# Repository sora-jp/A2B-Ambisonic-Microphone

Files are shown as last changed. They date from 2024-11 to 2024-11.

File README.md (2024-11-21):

# Passive Sonar / Ambisonic Microphone
This repo contains a design for a working ambisonic microphone, based on AD2427W A2B transcievers, along with Infineon IM73D122V01XTMA1 MEMS microphones.

## Structure
- kicad_micboard/ : Design files for the microphone board (firmware supports up to 16 of these)
- kicad_iface/ : Design files for the MCHStreamer interface board (only one of these needed)
- firmware_iface/ : Firmware for the MCHStreamer interface board

These folders each contain a README.md, describing their contents in more detail, along with an ORDERING.md giving details on how to order each board.

## Cabling
The cables between nodes are **straight-through twisted pair 2-pin JST-PH** cables. I crimped these cables myself, but you could easily order single-ended pre-crimped cables and then twist and solder them manually

## Known issues
- The voltage given to the interface board dictates how many nodes you can connect in series. For 5 volts, it can only support 6 nodes. For 15 nodes, you need to power the interface board with between 8V and 9V. It will *probably* work on 10V, but won't work on 12V. Some cheap 9V power supplies output *way* more than 9V when unloaded, so be careful with what power supply you choose.
- The A2B transciever on the interface board is missing connections for the I2C address lines. In theory, the actual I2C address of the transciever is undefined, in practice it works. If it doesn't, change the I2C address in the firmware.

## Future work
- The microphone boards have an expansion port, allowing the system to support up to 32 microphones (in theory, this hasn't been tested). The daughter-board to connect to said port hasn't been designed yet.
- The firmware is still very early, and doesn't correctly handle every edgecase. Ideally it should do line-fault diagnostics, but this is currently not implemented.

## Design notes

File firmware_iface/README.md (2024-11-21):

# Interface firmware
The following is a step-by-step guide on how to install and use the firmware.

## Building
To build the firmware from souce, first install `avr-gcc`, `avrdude`, `cmake`, and `make`
Then, run the following commands in this folder:
```sh
mkdir -p build
cd build
cmake ..
make
```

## Setting the fuses
The AVR microcontroller on the interface board needs the correct fuses programmed to work. This is handled automatically when flashing the board using `make flash`

## Flashing
To flash the firmware, first connect your AVRISP-MKII to the interface board. Make sure you are supplying 9V power to the interface board. Then, run `make flash` inside the build directory

## NixOS
If you are using Nix / running NixOS, you can use the included flake to install all necessary dependencies. Simply run `nix develop .#` in this directory, and all necessary tools will be installed and made available in your current shell.

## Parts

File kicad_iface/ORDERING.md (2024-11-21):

# Interface board ordering notes

I ordered this from JLCPCB with great success, and with the following non-default parameters:

- Impedance controlled: Yes
- Stackup: JLC7628
- Assembly: Yes
- Economic assembly (standard works but is more costly)

You might need standard assembly if you want JLC to solder the headers for you. Important to note that the headers (only the 2mm pitch ones, not the terminal block) are placed on the back side of the PCB.

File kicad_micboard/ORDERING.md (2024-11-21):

# Microphone board ordering notes

I ordered this from JLCPCB with the following non-standard parameters:

- Impedance controlled: Yes
- Stackup: JLC7628
- Assembly: Yes
- Economic assembly (standard works but is more costly)

All components can be placed with economic assembly

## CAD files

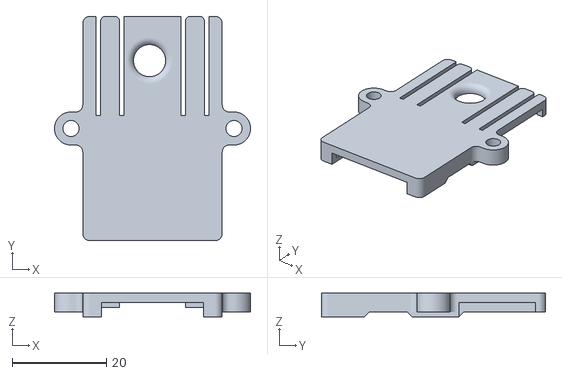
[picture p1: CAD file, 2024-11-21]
holder_cad/Backplane.obj
41.6 x 47.6 x 5.00

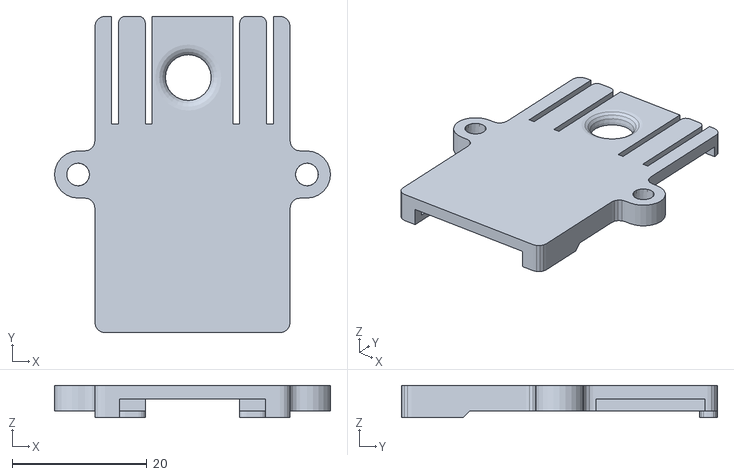
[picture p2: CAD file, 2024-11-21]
holder_cad/PassiveSonar/Backplane.obj
41.0 x 47.0 x 4.80

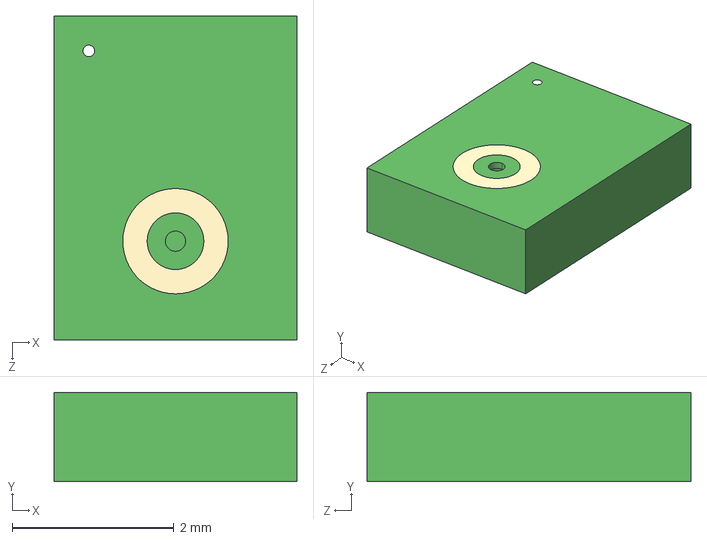
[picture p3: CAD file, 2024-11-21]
kicad_micboard/MP34DT06J.STEP
3.00 x 1.10 x 4.00 mm

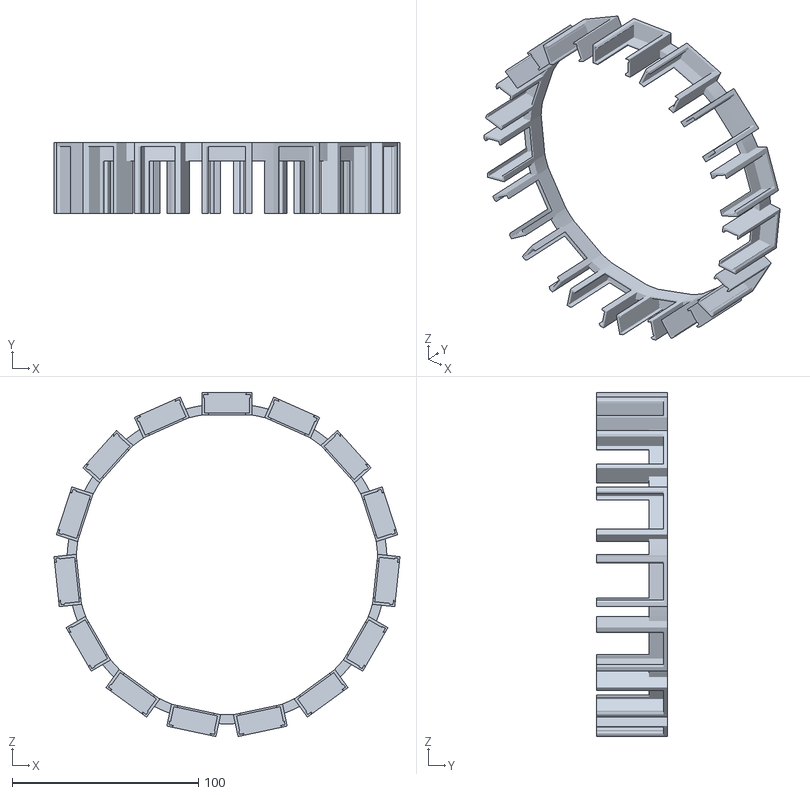
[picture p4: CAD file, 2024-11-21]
holder_cad/Sphere_V2.obj
185.8 x 38.0 x 184.8

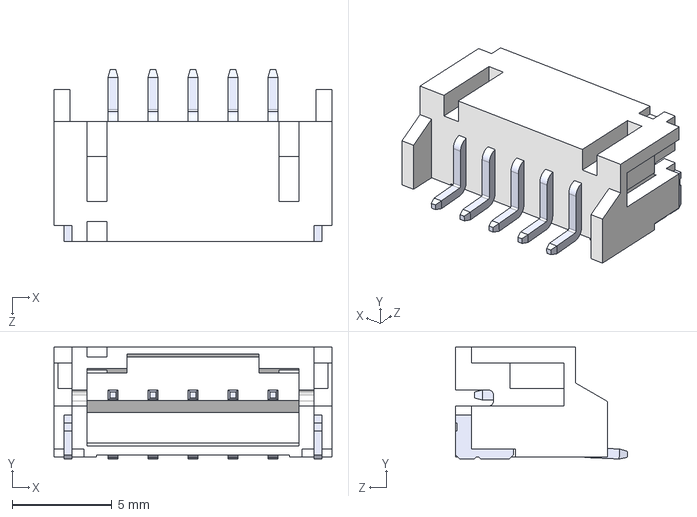
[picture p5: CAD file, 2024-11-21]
kicad_micboard/S5B-PH-SM4-TB--3DModel-STEP-56544.STEP
13.9 x 5.60 x 8.60 mm

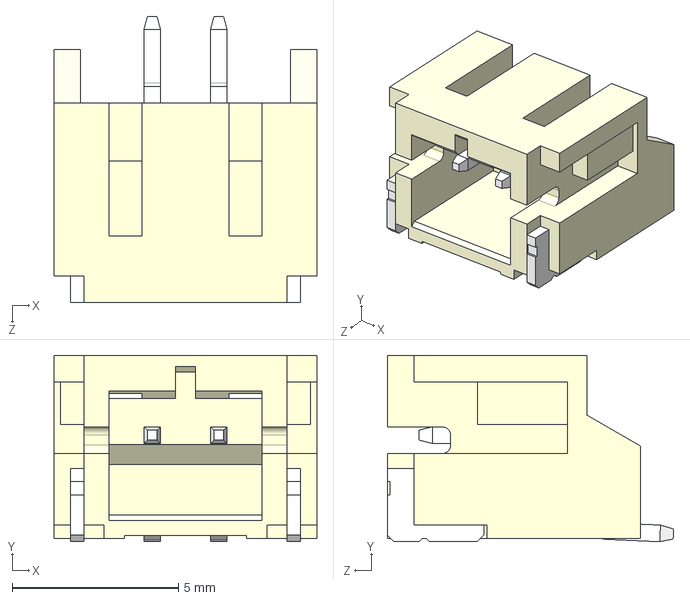
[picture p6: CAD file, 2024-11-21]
kicad_micboard/S2B-PH-SM4-TB--3DModel-STEP-269445.STEP
7.90 x 5.60 x 8.60 mm

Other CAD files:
holder_cad/Backplane.ipt
holder_cad/Backplate.ipt
holder_cad/PassiveSonar/PassiveSonar/ACT1210L-201-2P-TL00--3DModel-STEP-269445.iam
holder_cad/PassiveSonar/PassiveSonar/C_0402_1005Metric.iam
holder_cad/PassiveSonar/PassiveSonar/C_0402_1005Metric.ipt
holder_cad/PassiveSonar/PassiveSonar/C_0603_1608Metric.iam
holder_cad/PassiveSonar/PassiveSonar/C_0603_1608Metric.ipt
holder_cad/PassiveSonar/PassiveSonar/C_0805_2012Metric.iam
holder_cad/PassiveSonar/PassiveSonar/C_0805_2012Metric.ipt
holder_cad/PassiveSonar/PassiveSonar/D_SMA.iam
holder_cad/PassiveSonar/PassiveSonar/D_SMA.ipt
holder_cad/PassiveSonar/PassiveSonar/LED_0603_1608Metric.iam
holder_cad/PassiveSonar/PassiveSonar/LED_0603_1608Metric.ipt
holder_cad/PassiveSonar/PassiveSonar/L_0805_2012Metric.iam
holder_cad/PassiveSonar/PassiveSonar/L_0805_2012Metric.ipt
holder_cad/PassiveSonar/PassiveSonar/PassiveSonar_PCB.ipt
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

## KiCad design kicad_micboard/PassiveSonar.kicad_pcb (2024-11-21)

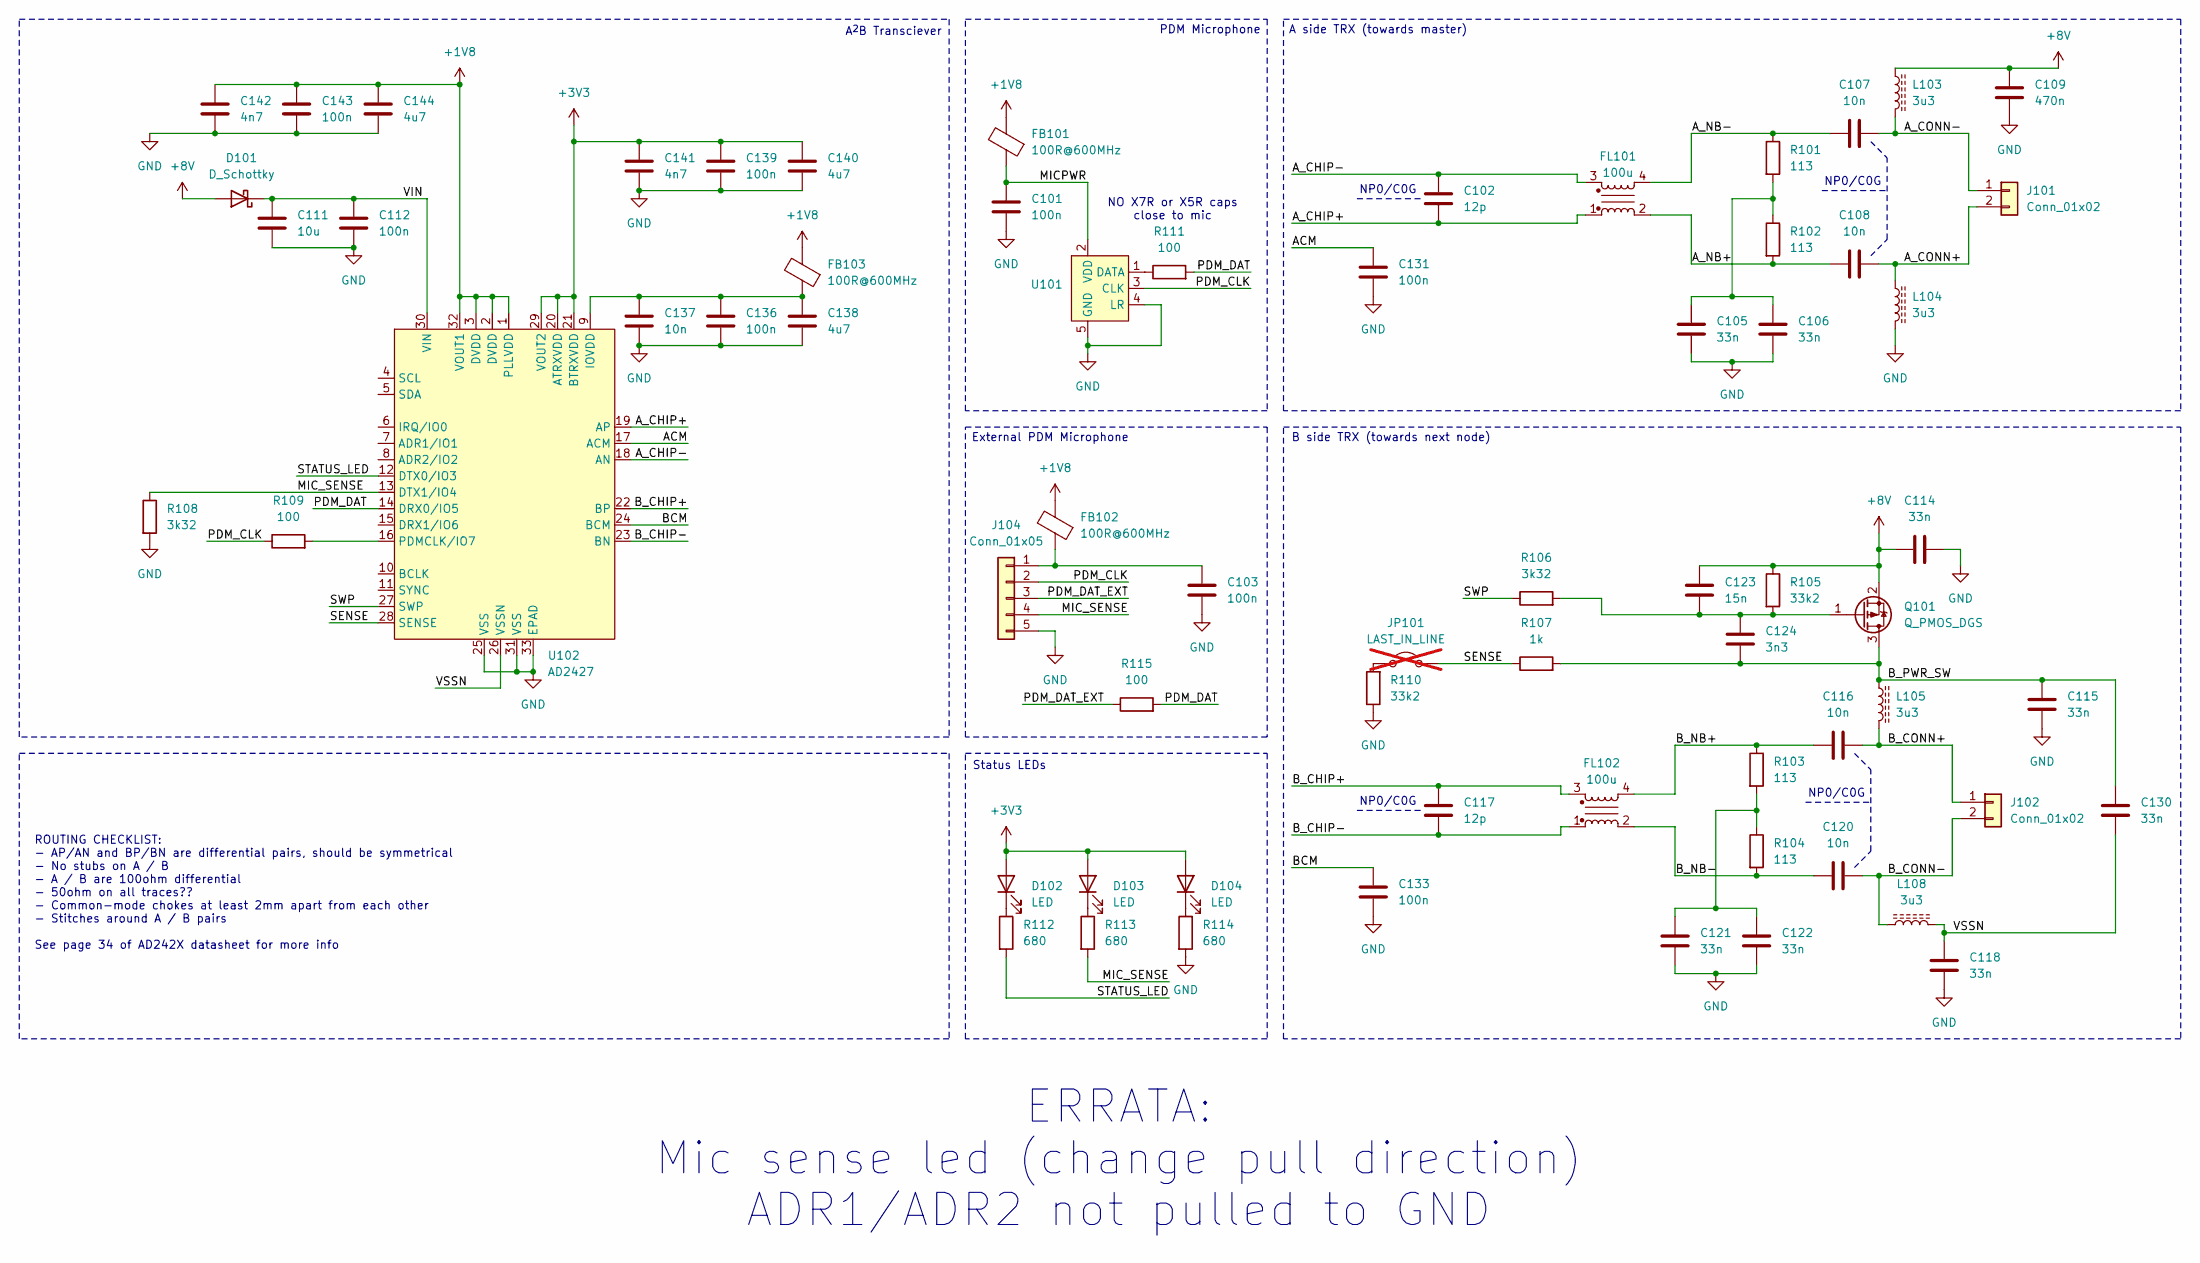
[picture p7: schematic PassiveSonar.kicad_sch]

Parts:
C101, C103, C112, C131, C133, C136, C139, C143: 100n; C_0402_1005Metric; JLC 0402
C102, C117: 12p; C_0402_1005Metric; JLC 0402
C105, C106, C114, C115, C118, C121, C122, C130: 33n; C_0603_1608Metric; JLC 0603
C107, C108, C116, C120, C137: 10n; C_0402_1005Metric; JLC 0402
C109: 470n; C_0805_2012Metric; JLC 0805
C111: 10u; C_0805_2012Metric; JLC 0805
C123: 15n; C_0603_1608Metric; JLC 0603
C124: 3n3; C_0402_1005Metric; JLC 0402
C138, C140, C144: 4u7; C_0603_1608Metric; JLC 0603
C141, C142: 4n7; C_0402_1005Metric; JLC 0402
D101: D_Schottky; D_SMA; JLC SMA(DO-214AC)
D102, D103, D104: LED; LED_0603_1608Metric; JLC 0603
FB101, FB102, FB103: 100R@600MHz; R_0603_1608Metric; JLC 0603
FL101, FL102: 100u; TDK-ACT1210L-101-2P-TL00; JLC SMD,3.9x2.5x2.5mm
J101, J102: Conn_01x02; JST_PH_S2B-PH-SM4-TB_1x02-1MP_P2.00mm_Horizontal; JLC SMD,P=2mm
J104: Conn_01x05; JST_PH_S5B-PH-SM4-TB_1x05-1MP_P2.00mm_Horizontal; JLC SMD
JP101: LAST_IN_LINE; PinHeader_1x02_P1.27mm_Vertical; not fitted
L103, L104, L105, L108: 3u3; L_0805_2012Metric; JLC 0805
Q101: Q_PMOS_DGS; SOT-23; JLC SOT-23
R101, R102, R103, R104: 113; R_0603_1608Metric; JLC 0603
R105, R110: 33k2; R_0402_1005Metric; JLC 0402
R106, R108: 3k32; R_0402_1005Metric; JLC 0402
R107: 1k; R_0402_1005Metric; JLC 0402
R109, R111, R115: 100; R_0402_1005Metric; JLC 0402
R112, R113, R114: 680; R_0402_1005Metric; JLC 0402
U101: Infineon_PG-LLGA-5-1; JLC SMD
U102: AD2427; LFCSP-32-1EP_5x5mm_P0.5mm_EP3.5x3.5mm; JLC LFCSP-32-SS(5x5)

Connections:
+1V8: C142.1, C143.1, C144.1, FB101.2, FB102.2, FB103.2, U102.1 (PLLVDD), U102.2 (DVDD), U102.3 (DVDD), U102.32 (VOUT1)
+3V3: C139.1, C140.1, C141.1, D102.2 (A), D103.2 (A), D104.2 (A), U102.20 (ATRXVDD), U102.21 (BTRXVDD), U102.29 (VOUT2)
+8V: C109.1, C114.1, C123.1, D101.2 (A), L103.1, Q101.2 (S), R105.1
/ACM: C131.1, U102.17 (ACM)
/A_CHIP+: C102.1, FL101.1, U102.19 (AP)
/A_CHIP-: C102.2, FL101.3, U102.18 (AN)
/A_CONN+: C108.1, J101.2, L104.1
/A_CONN-: C107.1, J101.1, L103.2
/A_NB+: C108.2, FL101.2, R102.2
/A_NB-: C107.2, FL101.4, R101.1
/BCM: C133.1, U102.24 (BCM)
/B_CHIP+: C117.2, FL102.3, U102.22 (BP)
/B_CHIP-: C117.1, FL102.1, U102.23 (BN)
/B_CONN+: C116.1, J102.1, L105.2
/B_CONN-: C120.1, J102.2, L108.1
/B_NB+: C116.2, FL102.4, R103.1
/B_NB-: C120.2, FL102.2, R104.2
/B_PWR_SW: C115.1, C124.2, C130.1, L105.1, Q101.3 (D), R107.2
/MICPWR: C101.2, FB101.1, U101.2 (VDD)
/MIC_SENSE: J104.4, R108.1, R113.2, U102.13 (DTX1/IO4)
/PDM_CLK: J104.2, R109.1, U101.3 (CLK)
/PDM_DAT: R111.2, R115.2, U102.14 (DRX0/IO5)
/PDM_DAT_EXT: J104.3, R115.1
/SENSE: JP101.2 (B), R107.1, U102.28 (SENSE)
/STATUS_LED: R112.2, U102.12 (DTX0/IO3)
/SWP: R106.1, U102.27 (SWP)
/VIN: C111.1, C112.1, D101.1 (K), U102.30 (VIN)
/VSSN: C118.1, C130.2, L108.2, U102.26 (VSSN)
GND: C101.1, C103.1, C105.1, C106.1, C109.2, C111.2, C112.2, C114.2, C115.2, C118.2, C121.1, C122.1, C131.2, C133.2, C136.2, C137.2, C138.2, C139.2, C140.2, C141.2, C142.2, C143.2, C144.2, J104.5, L104.2, R108.2, R110.1, R114.2, U101.4 (LR), U101.5 (GND), U102.25 (VSS), U102.31 (VSS), U102.33 (EPAD)
unnamed: C105.2, C106.2, R101.2, R102.1
unnamed: C121.2, C122.2, R103.2, R104.1
unnamed: D102.1 (K), R112.1
unnamed: D103.1 (K), R113.1
unnamed: D104.1 (K), R114.1
unnamed: C103.2, FB102.1, J104.1
unnamed: JP101.1 (A), R110.2
unnamed: C123.2, C124.1, Q101.1 (G), R105.2, R106.2
unnamed: R111.1, U101.1 (DATA)
unnamed: C136.1, C137.1, C138.1, FB103.1, U102.9 (IOVDD)
unnamed: R109.2, U102.16 (PDMCLK/IO7)

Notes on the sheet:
B side TRX (towards next node)
Status LEDs
ROUTING CHECKLIST: - AP/AN and BP/BN are differential pairs, should be symmetrical - No stubs on A / B - A / B are 100ohm differential - 50ohm on all traces?? - Common-mode chokes at least 2mm apart from each other - Stitches around A / B pairs See page 34 of AD242X datasheet for more info
NP0/C0G
A^{2}B Transciever
A side TRX (towards master)
PDM Microphone
NO X7R or X5R caps close to mic
External PDM Microphone
ERRATA: Mic sense led (change pull direction) ADR1/ADR2 not pulled to GND

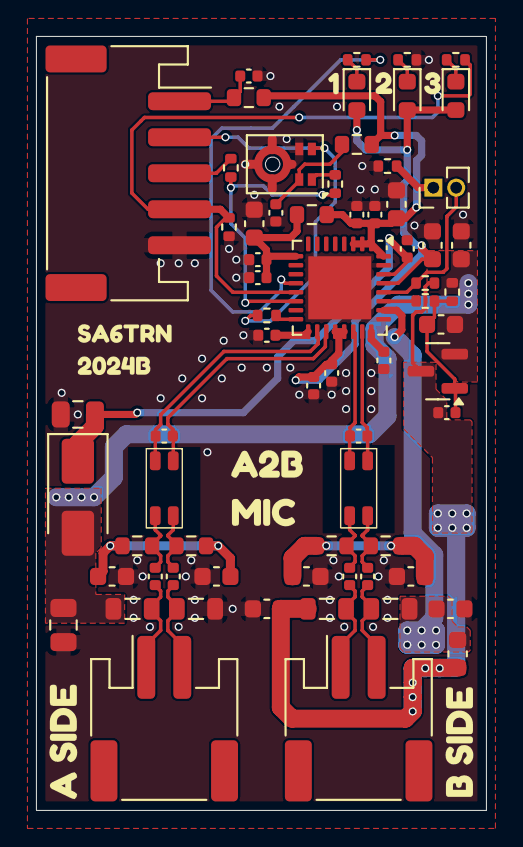
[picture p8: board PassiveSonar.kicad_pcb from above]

Board: 4 copper layers, 25.0 x 43.0 mm, 74 parts (0 on the bottom side), 40 nets.

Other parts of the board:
kibuzzard-66BA53B9: G***; kibuzzard-66BA53B9
kibuzzard-66BA534A: G***; kibuzzard-66BA534A
kibuzzard-66BA542A: G***; kibuzzard-66BA542A
kibuzzard-66BA5330: G***; kibuzzard-66BA5330
kibuzzard-66BA5382: G***; kibuzzard-66BA5382
kibuzzard-66BA5389: G***; kibuzzard-66BA5389
kibuzzard-66BA5390: G***; kibuzzard-66BA5390

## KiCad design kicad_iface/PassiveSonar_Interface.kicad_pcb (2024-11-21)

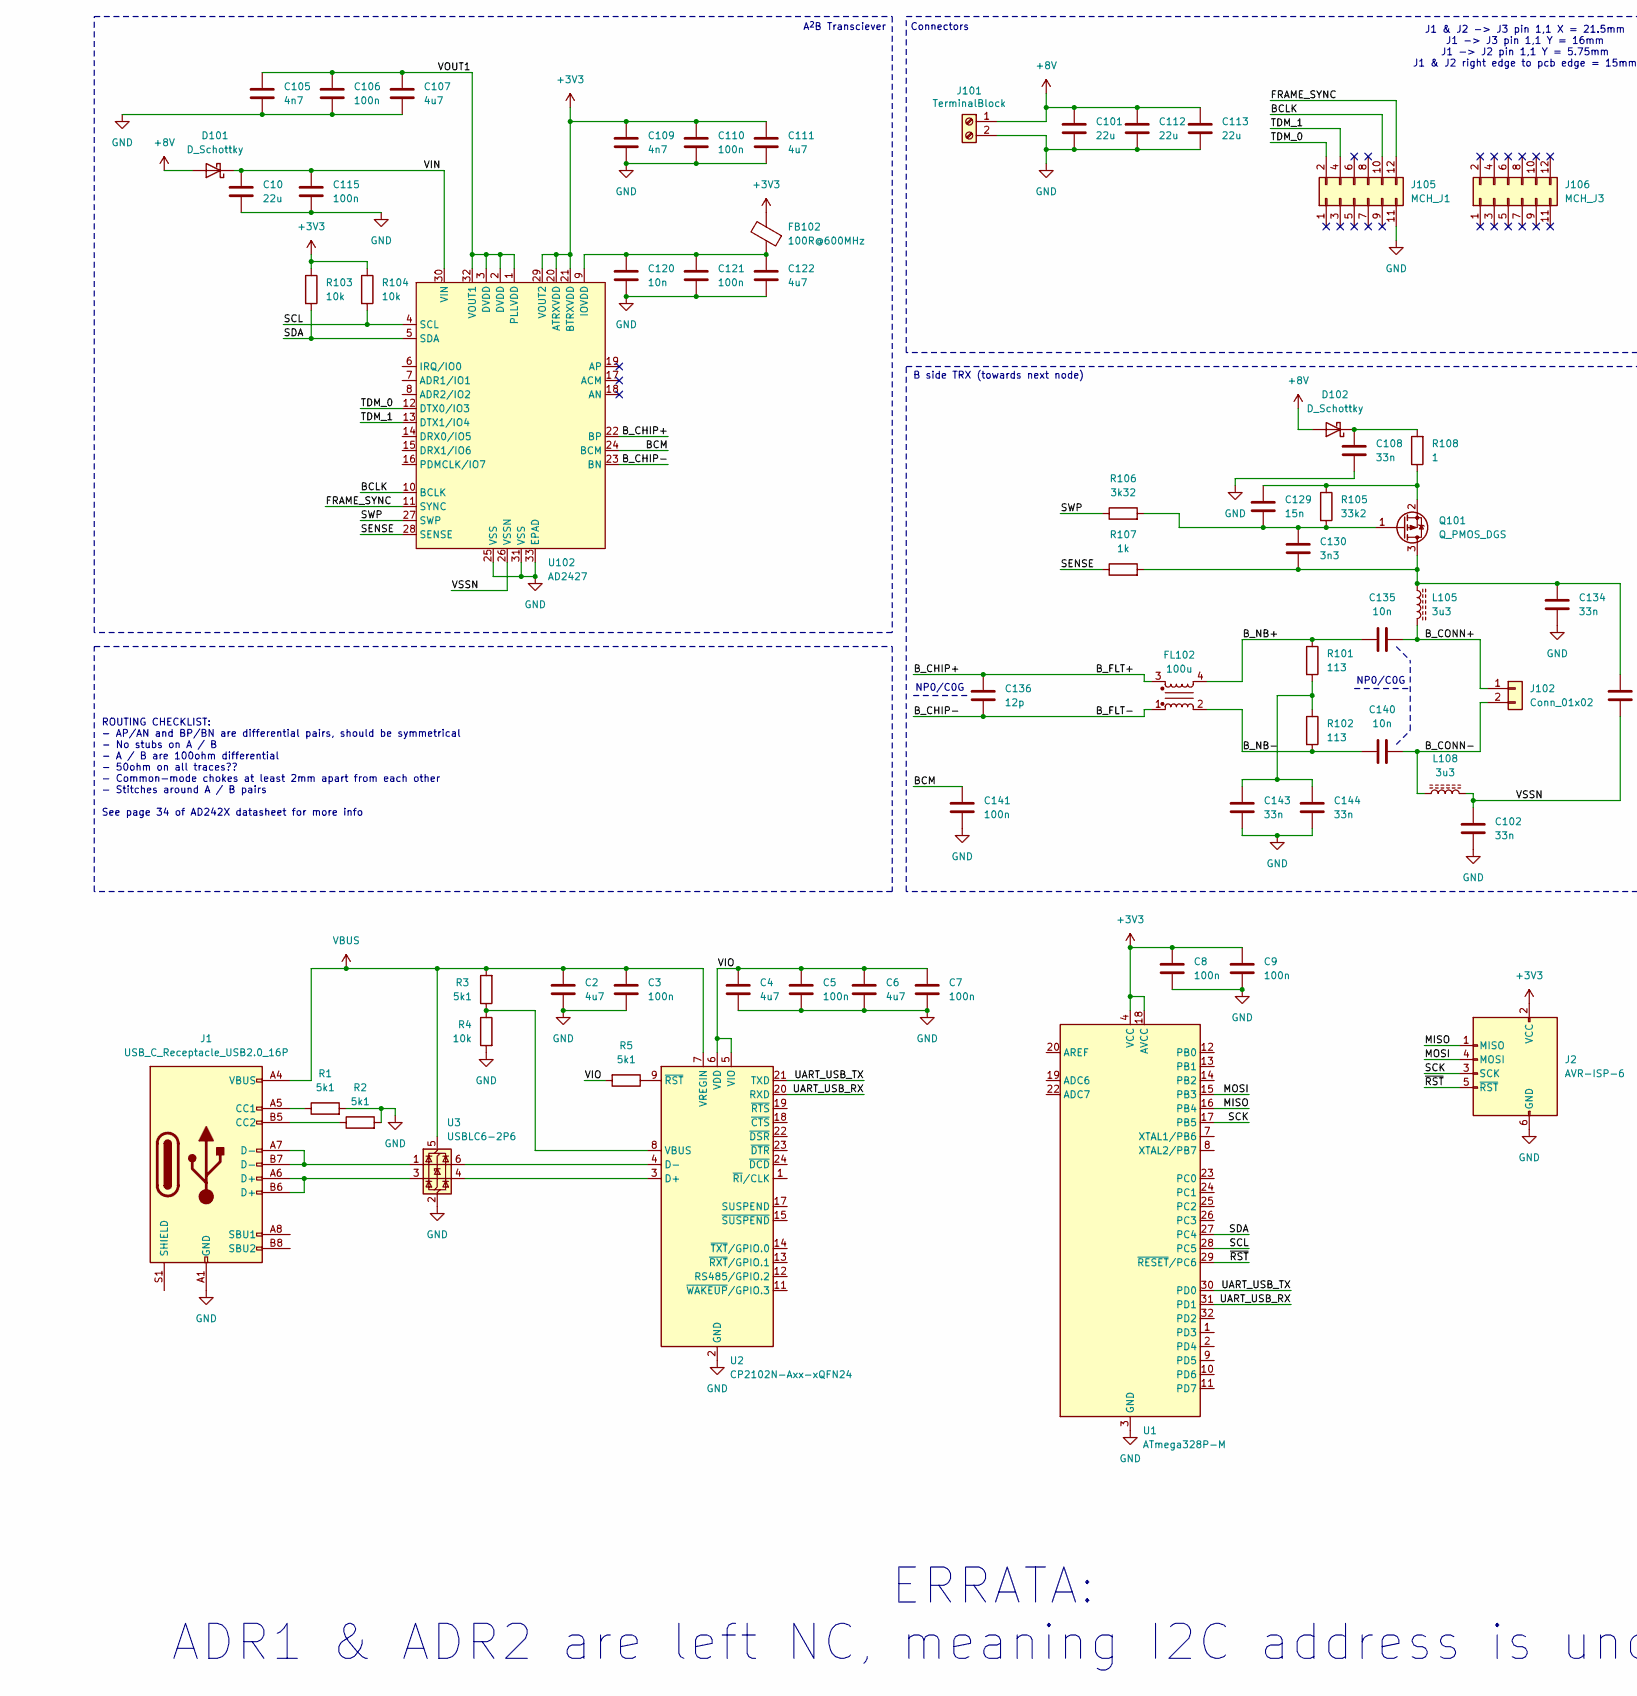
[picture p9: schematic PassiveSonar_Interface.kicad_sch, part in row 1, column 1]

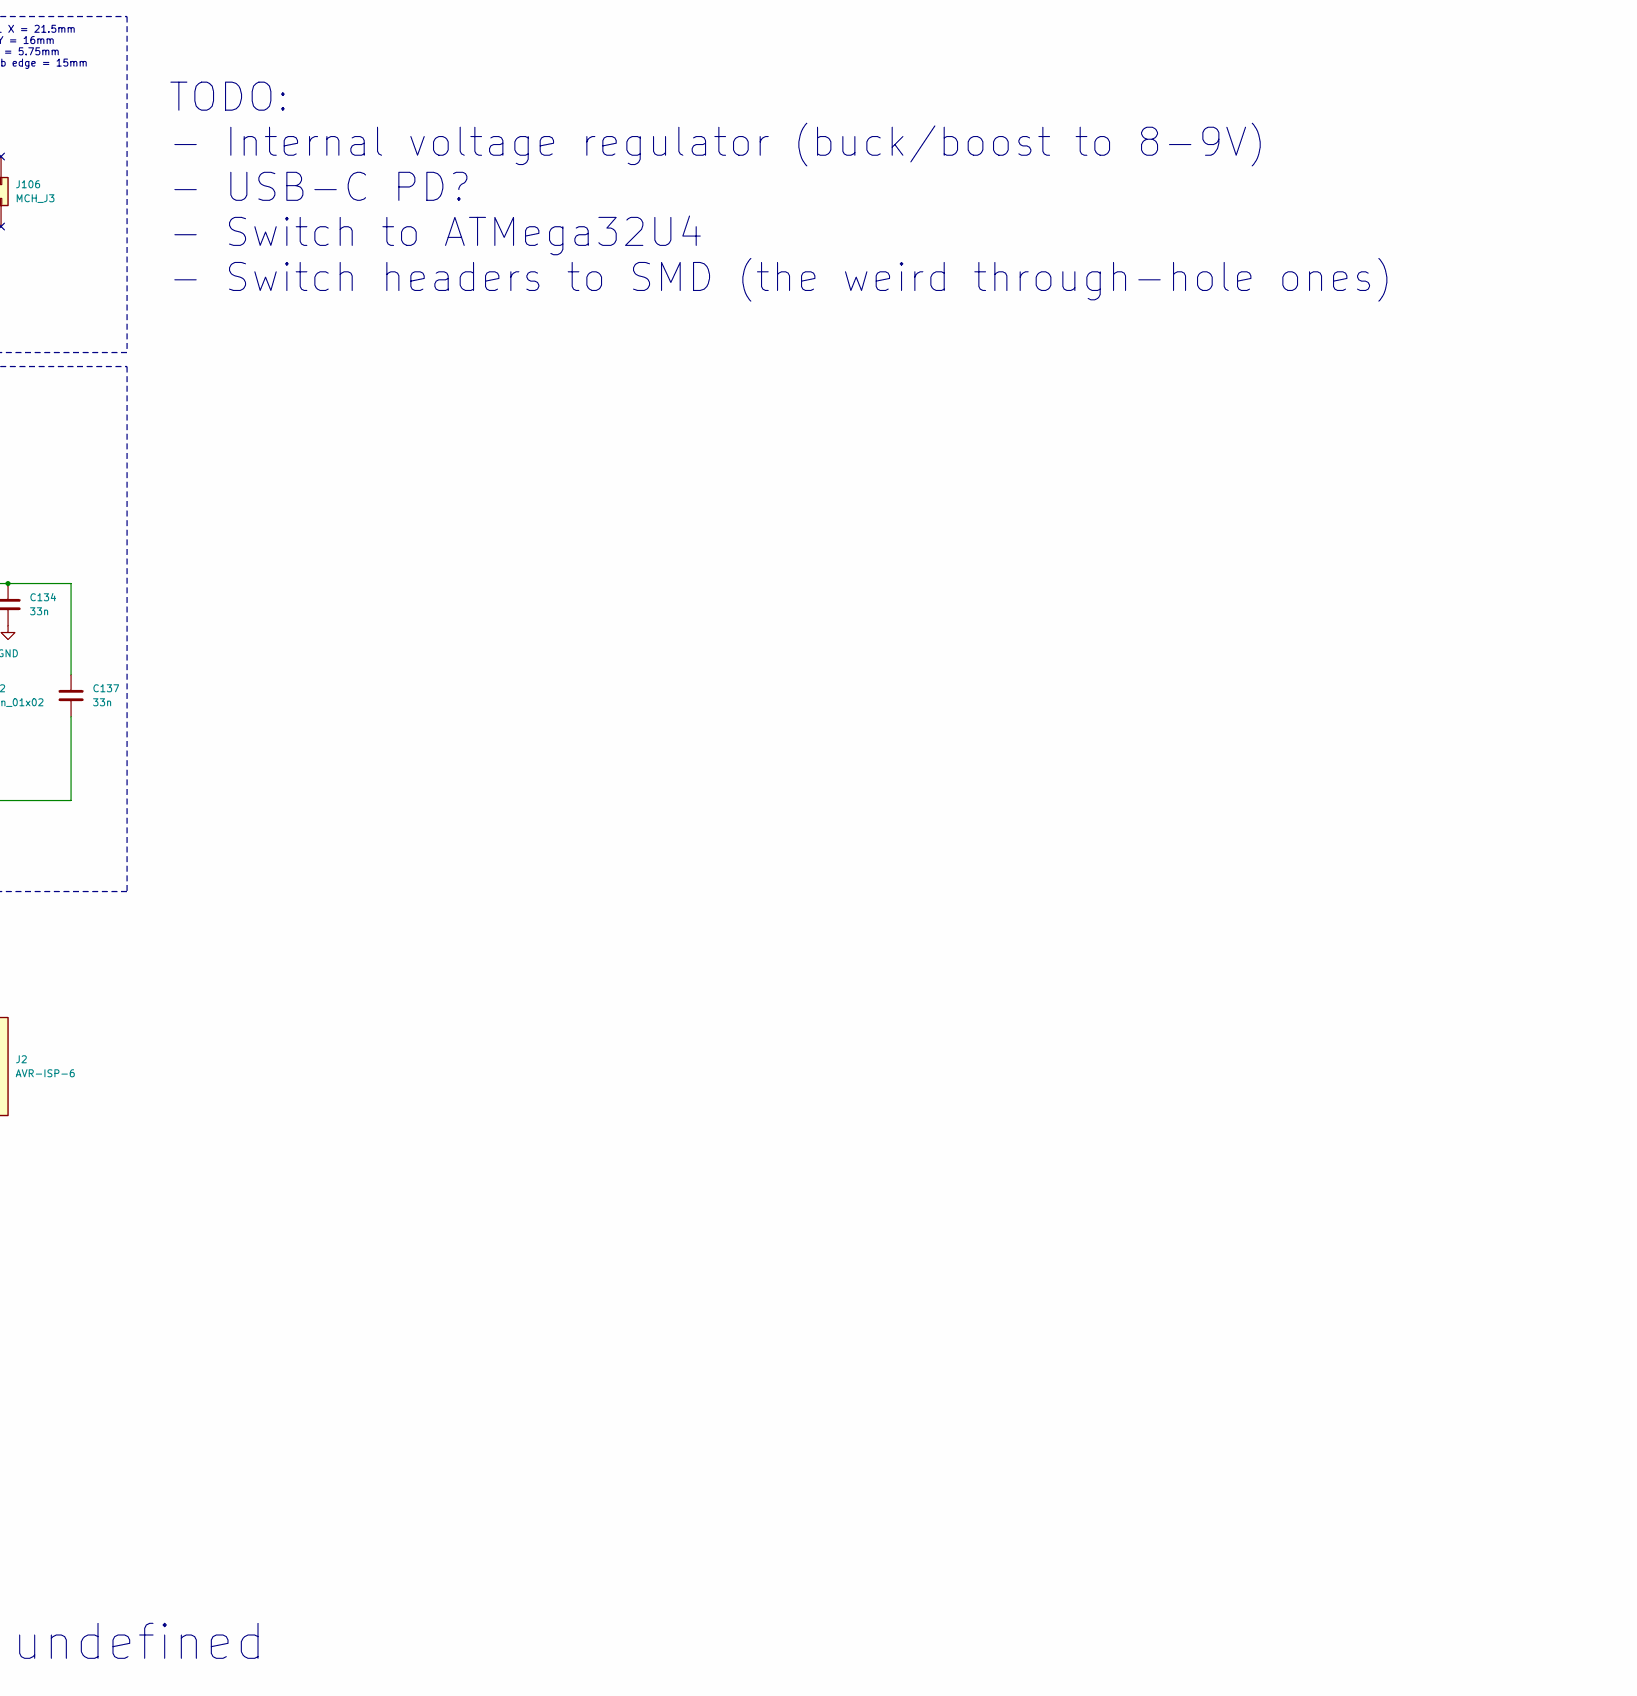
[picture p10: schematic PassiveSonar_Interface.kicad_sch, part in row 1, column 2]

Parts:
C2, C4, C6, C107, C111, C122: 4u7; C_0603_1608Metric; JLC 0603
C3, C5, C7, C8, C9, C106, C110, C115, C121, C141: 100n; C_0402_1005Metric; JLC 0402
C10, C101, C112, C113: 22u; C_0805_2012Metric; JLC 0805
C102, C108, C134, C137, C143, C144: 33n; C_0603_1608Metric; JLC 0603
C105, C109: 4n7; C_0402_1005Metric; JLC 0402
C120, C135, C140: 10n; C_0402_1005Metric; JLC 0402
C129: 15n; C_0603_1608Metric; JLC 0603
C130: 3n3; C_0402_1005Metric; JLC 0402
C136: 12p; C_0402_1005Metric; JLC 0402
D101, D102: D_Schottky; D_SMA; JLC SMA(DO-214AC)
FB102: 100R@600MHz; R_0603_1608Metric; JLC 0603
FL102: 100u; TDK-ACT1210L-101-2P-TL00; JLC SMD,3.9x2.5x2.5mm
J1: USB_C_Receptacle_USB2.0_16P; USB_C_Receptacle_HRO_TYPE-C-31-M-12; JLC SMD
J2: AVR-ISP-6; PinHeader_2x03_P2.54mm_Vertical_SMD; LCSC C124390
J101: TerminalBlock; TerminalBlock_Phoenix_MKDS-1,5-2_1x02_P5.00mm_Horizontal
J102: Conn_01x02; JST_PH_S2B-PH-SM4-TB_1x02-1MP_P2.00mm_Horizontal; JLC SMD,P=2mm
J105: MCH_J1; PinSocket_2x06_P2.00mm_Vertical; Mouser 872631223
J106: MCH_J3; PinSocket_2x06_P2.00mm_Vertical; Mouser 872631223
L105, L108: 3u3; L_0805_2012Metric; JLC 0805
Q101: Q_PMOS_DGS; SOT-23; JLC SOT-23
R1, R2, R3, R5: 5k1; R_0402_1005Metric; JLC 0402
R4, R103, R104: 10k; R_0402_1005Metric; JLC 0402
R101, R102: 113; R_0603_1608Metric; JLC 0603
R105: 33k2; R_0402_1005Metric; JLC 0402
R106: 3k32; R_0402_1005Metric; JLC 0402
R107: 1k; R_0402_1005Metric; JLC 0402
R108: 1; R_1206_3216Metric; JLC 1206
U1: ATmega328P-M; QFN-32-1EP_5x5mm_P0.5mm_EP3.1x3.1mm; JLC VQFN-32(5x5)
U2: CP2102N-Axx-xQFN24; QFN-24-1EP_4x4mm_P0.5mm_EP2.6x2.6mm; JLC QFN-24-EP(4x4)
U3: USBLC6-2P6; SOT-666; JLC SOT-666-6
U102: AD2427; LFCSP-32-1EP_5x5mm_P0.5mm_EP3.5x3.5mm; JLC LFCSP-32-SS(5x5)

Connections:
+3V3: C8.1, C9.1, C109.1, C110.1, C111.1, FB102.2, J2.2 (VCC), R103.1, R104.1, U1.4 (VCC), U1.6 (VCC), U1.18 (AVCC), U102.20 (ATRXVDD), U102.21 (BTRXVDD), U102.29 (VOUT2)
+8V: C101.1, C112.1, C113.1, D101.2 (A), D102.2 (A), J101.1
/BCLK: J105.10, U102.10 (BCLK)
/BCM: C141.1, U102.24 (BCM)
/B_CHIP+: C136.2, FL102.3, U102.22 (BP)
/B_CHIP-: C136.1, FL102.1, U102.23 (BN)
/B_CONN+: C135.1, J102.1, L105.2
/B_CONN-: C140.1, J102.2, L108.1
/B_NB+: C135.2, FL102.4, R101.1
/B_NB-: C140.2, FL102.2, R102.2
/FRAME_SYNC: J105.12, U102.11 (SYNC)
/MISO: J2.1 (MISO), U1.16 (PB4)
/MOSI: J2.4 (MOSI), U1.15 (PB3)
/SCK: J2.3 (SCK), U1.17 (PB5)
/SCL: R104.2, U1.28 (PC5), U102.4 (SCL)
/SDA: R103.2, U1.27 (PC4), U102.5 (SDA)
/SENSE: R107.1, U102.28 (SENSE)
/SWP: R106.1, U102.27 (SWP)
/TDM_0: J105.2, U102.12 (DTX0/IO3)
/TDM_1: J105.4, U102.13 (DTX1/IO4)
/UART_USB_RX: U1.31 (PD1), U2.20 (RXD)
/UART_USB_TX: U1.30 (PD0), U2.21 (TXD)
/VIN: C10.1, C115.1, D101.1 (K), U102.30 (VIN)
/VIO: C4.1, C5.1, C6.1, C7.1, R5.2, U2.5 (VIO), U2.6 (VDD)
/VOUT1: C105.1, C106.1, C107.1, U102.1 (PLLVDD), U102.2 (DVDD), U102.3 (DVDD), U102.32 (VOUT1)
/VSSN: C102.1, C137.2, L108.2, U102.26 (VSSN)
/~RST: J2.5 (~RST), U1.29 (~RESET/PC6)
GND: C2.2, C3.2, C4.2, C5.2, C6.2, C7.2, C8.2, C9.2, C10.2, C101.2, C102.2, C105.2, C106.2, C107.2, C108.1, C109.2, C110.2, C111.2, C112.2, C113.2, C115.2, C120.2, C121.2, C122.2, C134.2, C141.2, C143.1, C144.1, J1.A1 (GND), J1.A12 (GND), J1.B1 (GND), J1.B12 (GND), J2.6 (GND), J101.2, J105.11, R1.2, R2.2, R4.2, U1.3 (GND), U1.5 (GND), U1.21 (GND), U1.33 (GND), U2.2 (GND), U2.25 (GND), U3.2 (GND), U102.25 (VSS), U102.31 (VSS), U102.33 (EPAD)
unnamed: C143.2, C144.2, R101.2, R102.1
unnamed: C108.2, D102.1 (K), R108.2
unnamed: J1.A5 (CC1), R1.1
unnamed: J1.B5 (CC2), R2.1
unnamed: J1.A6 (D+), J1.B6 (D+), U3.3 (I/O2)
unnamed: J1.A7 (D-), J1.B7 (D-), U3.1 (I/O1)
unnamed: C130.2, C134.1, C137.1, L105.1, Q101.3 (D), R107.2
unnamed: C129.2, C130.1, Q101.1 (G), R105.2, R106.2
unnamed: C129.1, Q101.2 (S), R105.1, R108.1
unnamed: U2.3 (D+), U3.4 (I/O2)
unnamed: U2.4 (D-), U3.6 (I/O1)
unnamed: R3.1, R4.1, U2.8 (VBUS)
unnamed: R5.1, U2.9 (~RST)
unnamed: C120.1, C121.1, C122.1, FB102.1, U102.9 (IOVDD)
VBUS: C2.1, C3.1, J1.A4 (VBUS), J1.A9 (VBUS), J1.B4 (VBUS), J1.B9 (VBUS), R3.2, U2.7 (VREGIN), U3.5 (VBUS)

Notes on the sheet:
Connectors
ROUTING CHECKLIST: - AP/AN and BP/BN are differential pairs, should be symmetrical - No stubs on A / B - A / B are 100ohm differential - 50ohm on all traces?? - Common-mode chokes at least 2mm apart from each other - Stitches around A / B pairs See page 34 of AD242X datasheet for more info
B side TRX (towards next node)
TODO: - Internal voltage regulator (buck/boost to 8-9V) - USB-C PD? - Switch to ATMega32U4 - Switch headers to SMD (the weird through-hole ones)
A^{2}B Transciever
NP0/C0G
ERRATA: ADR1 & ADR2 are left NC, meaning I2C address is undefined
J1 & J2 -> J3 pin 1,1 X = 21.5mm J1 -> J3 pin 1,1 Y = 16mm J1 -> J2 pin 1,1 Y = 5.75mm J1 & J2 right edge to pcb edge = 15mm

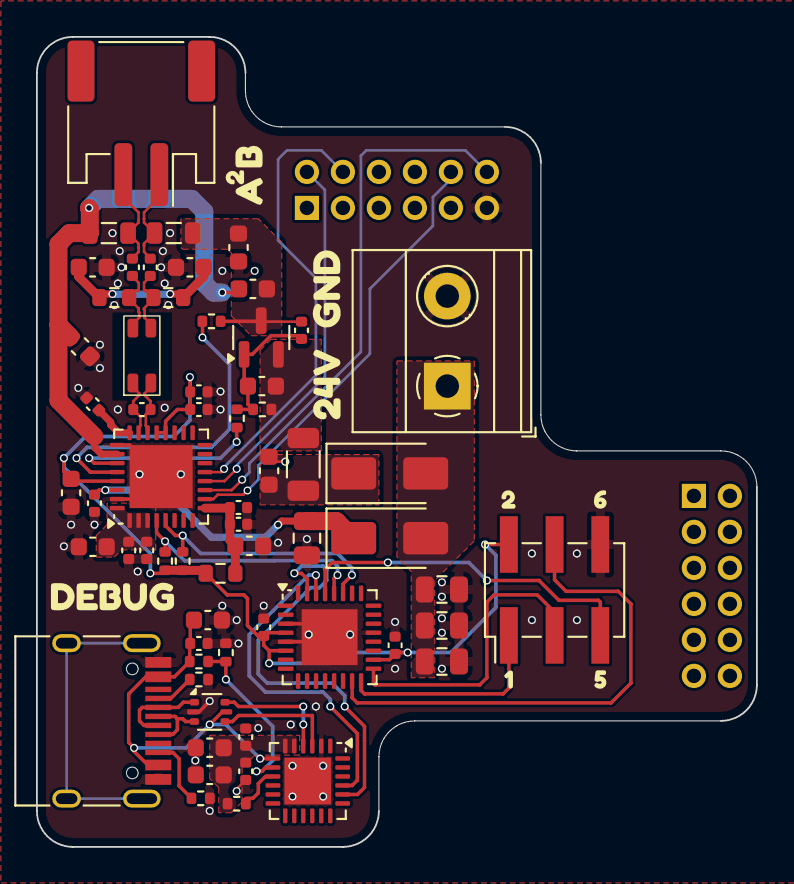
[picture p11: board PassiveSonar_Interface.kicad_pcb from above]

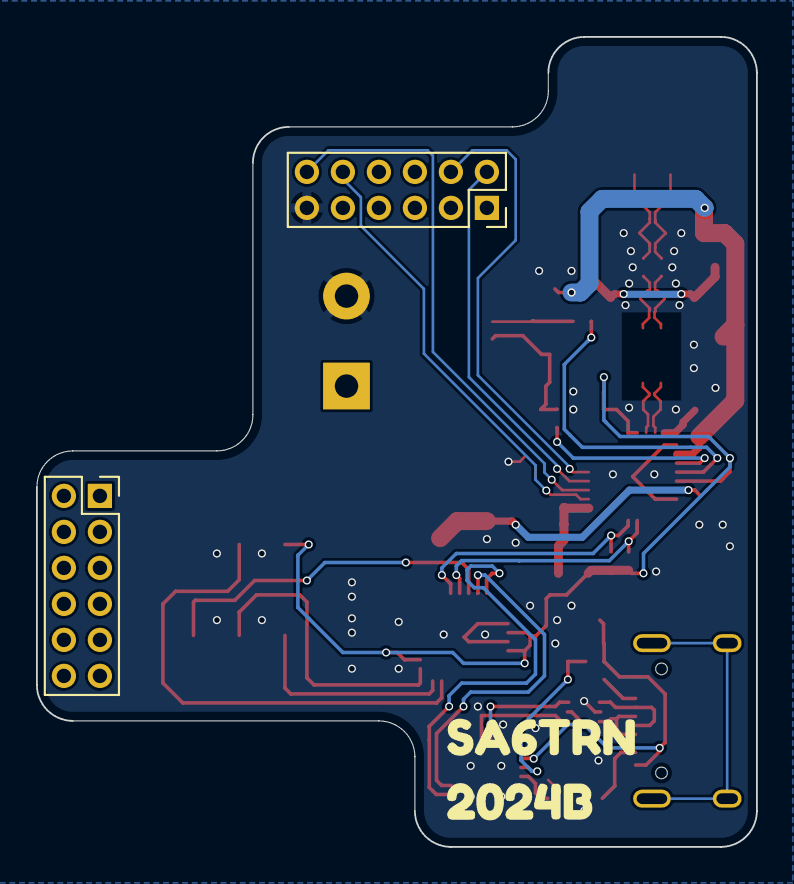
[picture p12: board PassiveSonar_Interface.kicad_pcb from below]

Board: 4 copper layers, 40.0 x 45.0 mm, 74 parts (3 on the bottom side), 43 nets.

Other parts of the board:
kibuzzard-66D2F73E: G***; kibuzzard-66D2F73E
kibuzzard-66D2F76B: G***; kibuzzard-66D2F76B
kibuzzard-66D2F77A: G***; kibuzzard-66D2F77A
kibuzzard-66D2F748: G***; kibuzzard-66D2F748
kibuzzard-66D2F788: G***; kibuzzard-66D2F788
kibuzzard-66D2F791: G***; kibuzzard-66D2F791
kibuzzard-66D2F797: G***; kibuzzard-66D2F797
kibuzzard-66D88E33: G***; kibuzzard-66D88E33
kibuzzard-66D3000E: G***; kibuzzard-66D3000E
kibuzzard-66D30007: G***; kibuzzard-66D30007

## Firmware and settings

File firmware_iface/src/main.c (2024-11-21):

#include "usart.h"
#include "time.h"
#include "printf.h"
#include "a2b.h"
#include "i2c.h"
#include "log.h"

int main(void) {
    usart_initialize();
    dlog("BOOT!");

    time_init();
    i2c_init(100000);

    dlog("Discovering bus");
    a2b_set_rc(0x6c);
    a2b_init_master();
    a2b_discover_configure_bus();
    a2b_main_loop();
}

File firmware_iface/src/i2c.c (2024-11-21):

#include "i2c.h"
#include <avr/io.h>
#include <avr/builtins.h>
#include <util/twi.h>
#include "printf.h"

static const uint8_t prescaler_lut[] = {1, 4, 16, 64};

#define BIT(x) (1 << (x))
#define TWCR_CLEAR (BIT(TWINT) | BIT(TWEA) | BIT(TWEN))
#define TWCR_START (TWCR_CLEAR | BIT(TWSTA))
#define TWCR_STOP  (TWCR_CLEAR | BIT(TWSTO))

bool i2c_init(uint32_t freq) {
    uint8_t prescaler = 1;
    uint8_t divider = F_CPU / (16 + 2 * freq * prescaler_lut[prescaler]);

    TWSR = 2;
    TWBR = 12;

    //TWSR = prescaler & 0x03;
    //TWBR = divider;
    TWCR |= BIT(TWEN);
    TWCR |= BIT(TWINT);

    return 0;
}

static void tw_wait_int(void) {
    while ((TWCR & BIT(TWINT)) == 0) __asm__ volatile("");
}

static uint8_t tw_write_raw(uint8_t val) {
    TWDR = val;
    TWCR = TWCR_CLEAR;
    tw_wait_int();

    return TW_STATUS;
}

static uint8_t tw_start(void) {
    TWCR = TWCR_START;
    tw_wait_int();

    return TW_STATUS;
}

static uint8_t tw_stop(void) {
    TWCR = TWCR_STOP;
    //tw_wait_int();

    return TW_STATUS;
}

static uint8_t tw_read(bool ack) {
    if (ack) {
        TWCR = TWCR_CLEAR;
    }
    else {
        TWCR = TWCR_CLEAR & ~BIT(TWEA);
    }

    tw_wait_int();
    uint8_t data = TWDR;
    return data;
}

static uint8_t twi_calc_addr(uint8_t addr, bool write) {
    return (addr << 1) | (write ? 0 : 1);
}

int8_t i2c_write(uint8_t addr, uint8_t* data, uint8_t count, bool stop) {
    uint8_t res = tw_start();
    if (res != TW_START && res != TW_REP_START) return -1;

    res = tw_write_raw(twi_calc_addr(addr, true));
    if (res != TW_MR_SLA_ACK && res != TW_MT_SLA_ACK) {
        tw_stop();
        return -1;
    }

    for (uint8_t i = 0; i < count; i++) {
        res = tw_write_raw(*data++);
        if (res != TW_MT_DATA_ACK) {
            tw_stop();
            return -1;
        }
    }

    if (stop) tw_stop();

    return count;
}

int8_t i2c_read(uint8_t addr, uint8_t* data, uint8_t count, bool stop) {
    uint8_t res = tw_start();
    if (res != TW_START && res != TW_REP_START) return -1;

    res = tw_write_raw(twi_calc_addr(addr, false));
    if (res != TW_MR_SLA_ACK && res != TW_MT_SLA_ACK) {
        return -1;
    }

    for (uint8_t i = 0; i < count; i++) {
        *data++ = tw_read(i != count - 1);
        res = TWSR & ~0x03;
        if (res != TW_MR_DATA_ACK && res != TW_MR_DATA_NACK) {
            return -1;
        }
    }

    if (stop) tw_stop();

    return count;
}
